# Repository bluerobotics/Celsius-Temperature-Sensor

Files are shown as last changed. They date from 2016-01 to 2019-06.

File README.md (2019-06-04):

# Celsius Temperature Sensor

Arduino software library is available [here](http://github.com/bluerobotics/BlueRobotics_TSYS01_Library/).

The schematic and board layout are designed in EagleCAD.

## Description

High accuracy, fast time response subsea temperature sensor with I<sup>2</sup>C interface. It has a measurement accuracy of just &plusmn;0.1&deg;C.

The sensor is the Measurement Specialties TSYS01, It comes standard with a 4-pin DF13 connector and compatible with most DroneCode compatible boards including the APM2.6, PixHawk, and others.

## Features

* &plusmn;0.1&deg;C Accuracy
* Standard DF13 connector for connection to DroneCode boards such as APM, PixHawk, Navio2, etc.
* Sealed in a bulkhead penetrator for easy installation into any 10mm hole

## Compatibility

The Celsius sensor is compatible with any device with 3.3V I<sup>2</sup>C logic. When using with a 5V device, such as an Arduino Uno, it is necessary to use a logic level converter.

## Configuration

The sensor is mounted on a PCB that extends into the water and is sealed from water with a thick layer of thermally conductive epoxy. This mounting method minimizes heat capacitance and ensures a fast time-response.

## Ratings

For further information please see the [TSYS01 Data Sheet](http://meas-spec.com/downloads/TSYS01_Digital_Temperature_Sensor.pdf).

**Electrical:**

| **Item** | **Condition** | **Value** |
| ---: | :---: | --- |
| Supply Voltage | - | 3.3 to 5.5 volts |
| I<sup>2</sup>C Logic Voltage (SDA and SCL) | - | 3.3 volts |
| Peak Current | - | 1.4 mA |

**Temperature:**

| **Item** | **Condition** | **Value** |
| ---: | :---: | --- |
| Operating Temperature | - | -40 to +125&deg;C |
|Storage Temperature | - | -55 to +150&deg;C |
|Absolute Accuracy | From -5 to 50&deg;C | +/- 0.1&deg;C |
| | From -40 to 125&deg;C |  +/- 0.5&deg;C |

**Physical:**

| **Item** | **Condition** |
| ---: | :--- |
| Wire Colors | Green - I<sup>2</sup>C Clock (SCL, 3.3V) |
| | White - I<sup>2</sup>C Data (SDA, 3.3V)  |
| | Red - Positive (3.3-5.5V) |
| | Black - Ground |
| Overall Length | 56.1 mm |
| Thread Size | M10x1.5 20 mm threaded |
| Recommended Through Hole Size | 10-11 mm |
| Wrench Flats | 16 mm |

## Physical Specifications

* Bulkhead hole size: 10-10.5mm
* Wire length: 11" (280mm)

## License

The Celsius Pressure Sensor Hardware Design is released under the MIT License.

## Revision History

0.0 - Under development

0.1 - First production version (marked with rev3)

0.2 - Minor layout changes (marked with rev4)

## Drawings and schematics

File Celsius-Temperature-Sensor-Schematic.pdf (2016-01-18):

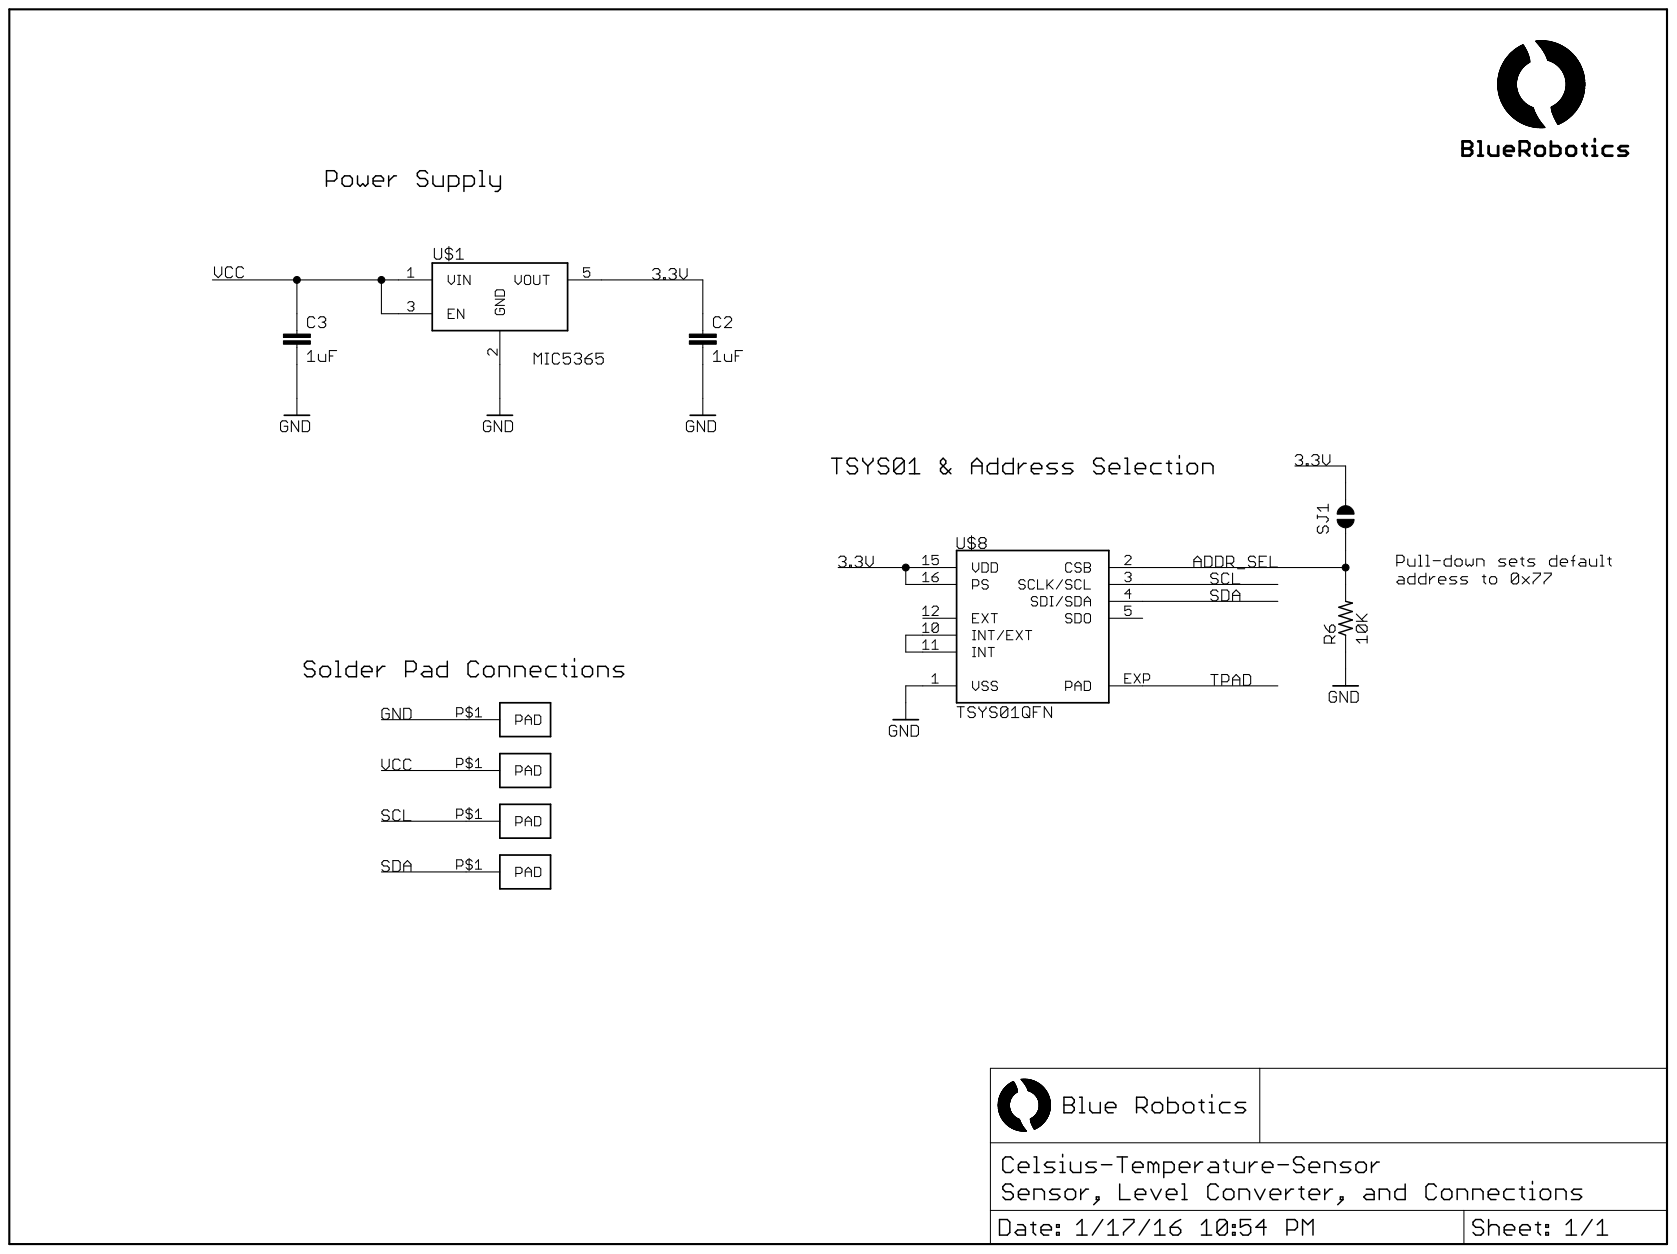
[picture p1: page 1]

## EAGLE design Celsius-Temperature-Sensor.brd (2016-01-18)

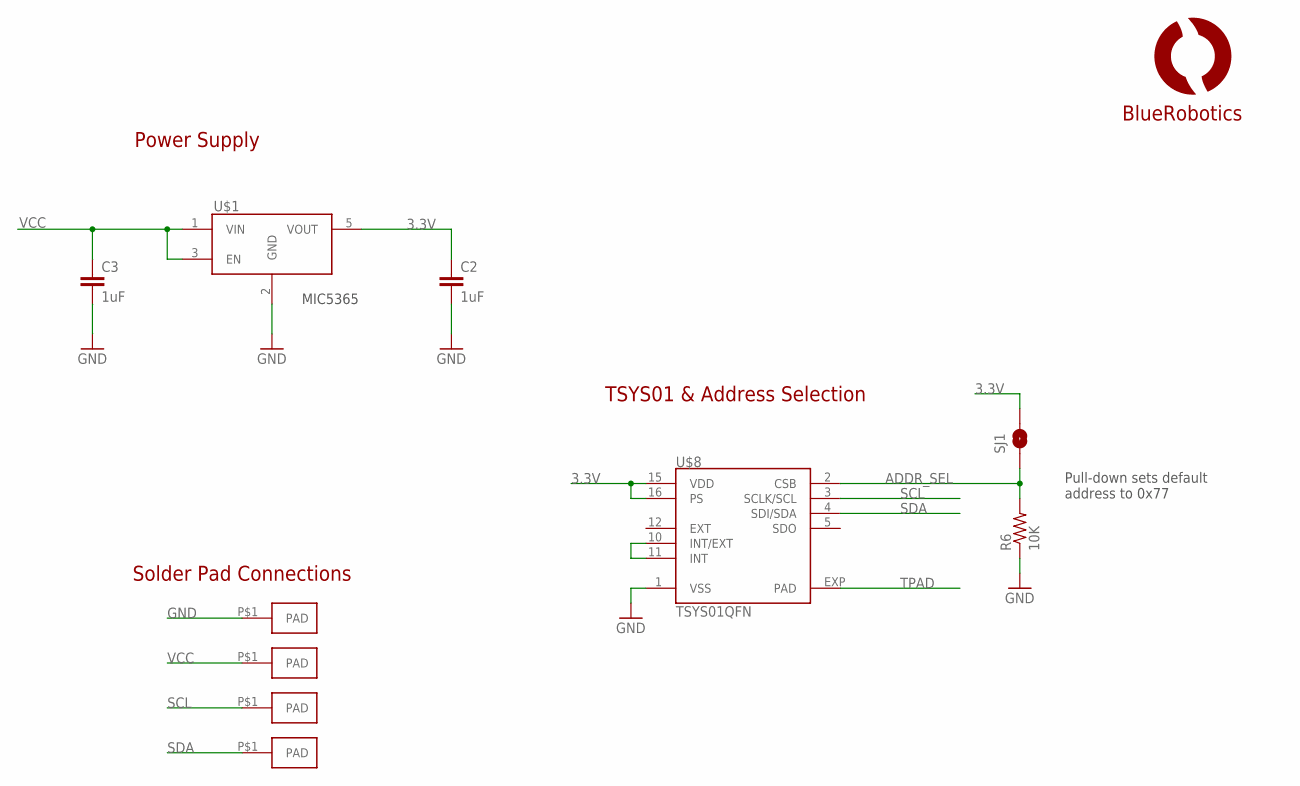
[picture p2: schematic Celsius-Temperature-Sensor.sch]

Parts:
C2, C3: 1uF; C0402
R6: 10K; R0402
SJ1: JUMPER-PAD-2-NO; PAD-JUMPER-2-NO_NO_SILK
U$1: VREG-MIC5365; SC70-5L
U$3, U$4, U$5, U$6: PAD1.5X3MM; PAD-1.5X3MM
U$7: LOGOBR-LOGO-S; BR-LOGO-SMALL
U$8: TSYS01QFN; QFN16-4X4

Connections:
3.3V: C2.1, SJ1.2, U$1.5 (VOUT), U$8.15 (VDD), U$8.16 (PS)
ADDR_SEL: R6.2, SJ1.1, U$8.2 (CSB)
GND: C2.2, C3.2, R6.1, U$1.2 (GND), U$3.P$1, U$8.1 (VSS)
unnamed: U$8.10 (INT/EXT), U$8.11 (INT)
SCL: U$5.P$1, U$8.3 (SCLK/SCL)
SDA: U$6.P$1, U$8.4 (SDI/SDA)
TPAD: U$8.EXP (PAD)
VCC: C3.1, U$1.1 (VIN), U$1.3 (EN), U$4.P$1

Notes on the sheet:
Solder Pad Connections
TSYS01 & Address Selection
Power Supply
MIC5365
Pull-down sets default address to 0x77

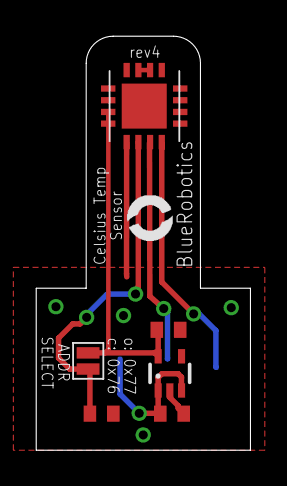
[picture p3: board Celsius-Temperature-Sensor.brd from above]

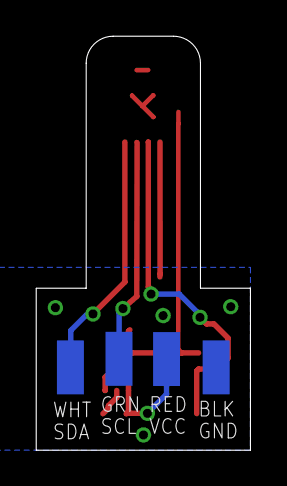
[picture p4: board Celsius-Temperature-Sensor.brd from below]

Board: 2 copper layers, 11.9 x 23.0 mm, 11 parts (4 on the bottom side), 7 nets.

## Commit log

2015-11-01 Added base initial files. The board outline is about to change dramatically.
    [Celsius-Temperature-Sensor.brd, Celsius-Temperature-Sensor.sch]
2015-11-01 Updated to new board outline. Still needs some fillets in the corners for machining.
    [Celsius-Temperature-Sensor.brd, Celsius-Temperature-Sensor.sch]
2015-11-02 Updated frame.
    [Celsius-Temperature-Sensor.brd, Celsius-Temperature-Sensor.sch]
2015-11-04 Updated zener to LDO.
    [Celsius-Temperature-Sensor.brd, Celsius-Temperature-Sensor.sch]
2015-11-16 Fixed incorrect regulator footprint. Stupid mistake.
    [Celsius-Temperature-Sensor.brd, Celsius-Temperature-Sensor.sch]
2015-12-16 Removed diode because it caused a large enough Vf to drop voltage outside of range needed to achieve high accuracy Acc1. Also added a few ground vias. Ordering production version from this revision.
    [Celsius-Temperature-Sensor.brd, Celsius-Temperature-Sensor.sch]
2016-01-10 Added PDF schematic, updated readme.
    [Celsius-Temperature-Sensor.sch]
2016-01-18 Fixed for compatibility with DroneCode autopilots.
    Removed logic level converters.
    [Celsius-Temperature-Sensor.brd, Celsius-Temperature-Sensor.sch]

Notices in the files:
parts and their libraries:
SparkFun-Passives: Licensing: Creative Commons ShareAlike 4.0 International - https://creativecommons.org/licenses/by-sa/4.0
